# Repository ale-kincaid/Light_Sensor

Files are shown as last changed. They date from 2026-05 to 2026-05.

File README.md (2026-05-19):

# Light Sensor Embedded System

This repository contains the firmware and documentation for a light-sensing embedded system built around an STM32 microcontroller and a custom PCB. The project originally began as a school embedded systems project and has since been transferred to this personal repository for continued development, documentation, and refinement.

The system is designed to measure light intensity using a light-to-frequency sensor, process the signal on an STM32 microcontroller, and support serial communication, timestamping, and data logging for future environmental monitoring use cases.

## Project Status

This project is currently being continued as a personal embedded systems project. The original prototype was developed using an STM32 Nucleo development board, and the current version is being adapted to run on a custom PCB.

Current focus areas include:

- Migrating the firmware from the development board setup to the custom PCB
- Verifying UART communication on the custom hardware
- Testing sensor measurements from the PCB-mounted light sensor
- Improving flash logging and timestamped data storage
- Preparing the system for a more complete standalone prototype

## Project Overview

The goal of this project is to build a compact embedded light sensor capable of collecting and storing light measurements. The system uses a light-to-frequency sensor whose output frequency changes based on the amount of detected light. The STM32 measures this frequency using timer input capture and can communicate with a user through a UART command interface.

This type of system could be used for environmental monitoring, light pollution studies, outdoor sensing, or as a foundation for a low-power remote sensor node.

## Features

- STM32-based embedded firmware
- Custom PCB-based hardware design
- Light-to-frequency sensor integration
- Timer input capture for measuring sensor output
- UART serial command interface
- Interrupt-driven UART receive handling
- Circular buffer for incoming commands
- Real-time clock support for timestamps
- Flash memory logging for persistent records
- Command parsing for setting and reading system values
- Prototype-focused hardware and firmware documentation

## Hardware

The current hardware design uses a custom PCB instead of only relying on the STM32 Nucleo development board. The PCB is designed to support the core sensing, communication, and power components needed for the light sensor prototype.

### Main Hardware Components

| Component | Purpose |
|---|---|
| STM32 microcontroller | Main embedded controller |
| TSL237 light-to-frequency sensor | Measures light through frequency output |
| Custom PCB | Integrates the sensor, controller, power, and communication hardware |
| UART connector | Serial communication and debugging |
| RTC support | Provides time and date information for logged records |
| Battery holder / power input | Supports standalone prototype development |
| Oscillator / clock components | Supports timing requirements |
| Debug/programming interface | Allows firmware flashing and debugging |

## Software / Firmware Stack

- **Language:** Embedded C
- **IDE:** STM32CubeIDE
- **Configuration Tool:** STM32CubeMX
- **Platform:** STM32
- **Communication:** UART
- **Key Peripherals:**
  - GPIO
  - UART / USART
  - Timers
  - RTC
  - Flash memory
  - Interrupts

## System Architecture

```text
Light Source
    |
    v
TSL237 Light-to-Frequency Sensor
    |
    v
STM32 Timer Input Capture
    |
    v
Embedded Firmware
    |
    +--> UART Command Interface
    |
    +--> RTC Timestamping
    |
    +--> Flash Data Logging
    |
    v
Stored or Transmitted Sensor Records

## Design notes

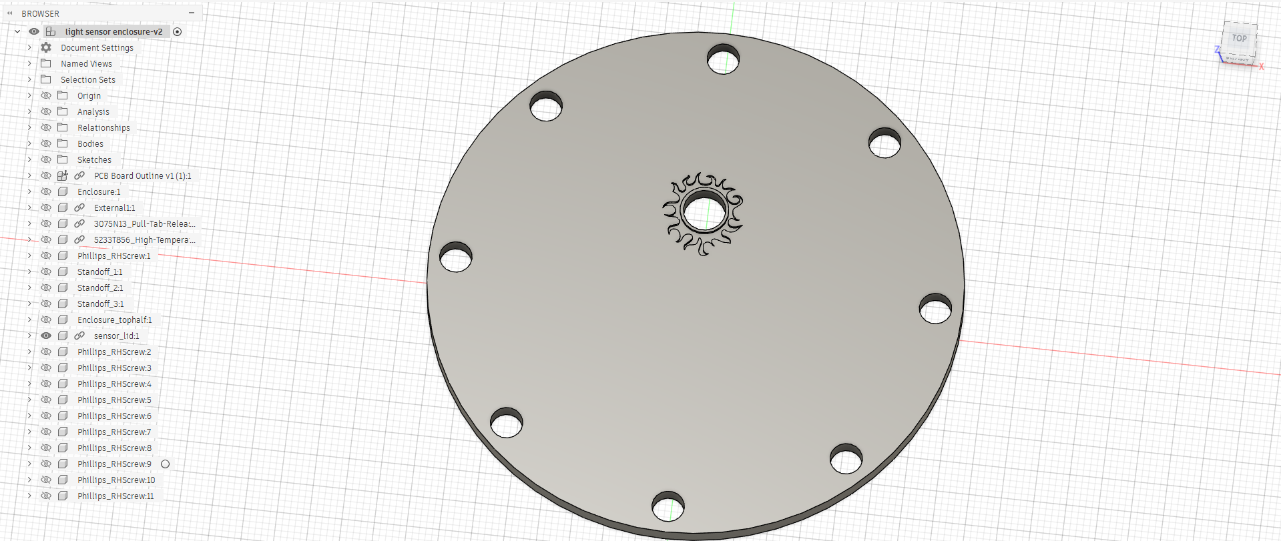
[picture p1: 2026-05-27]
AutodeskFusion/light_sensor_lid_sc.png

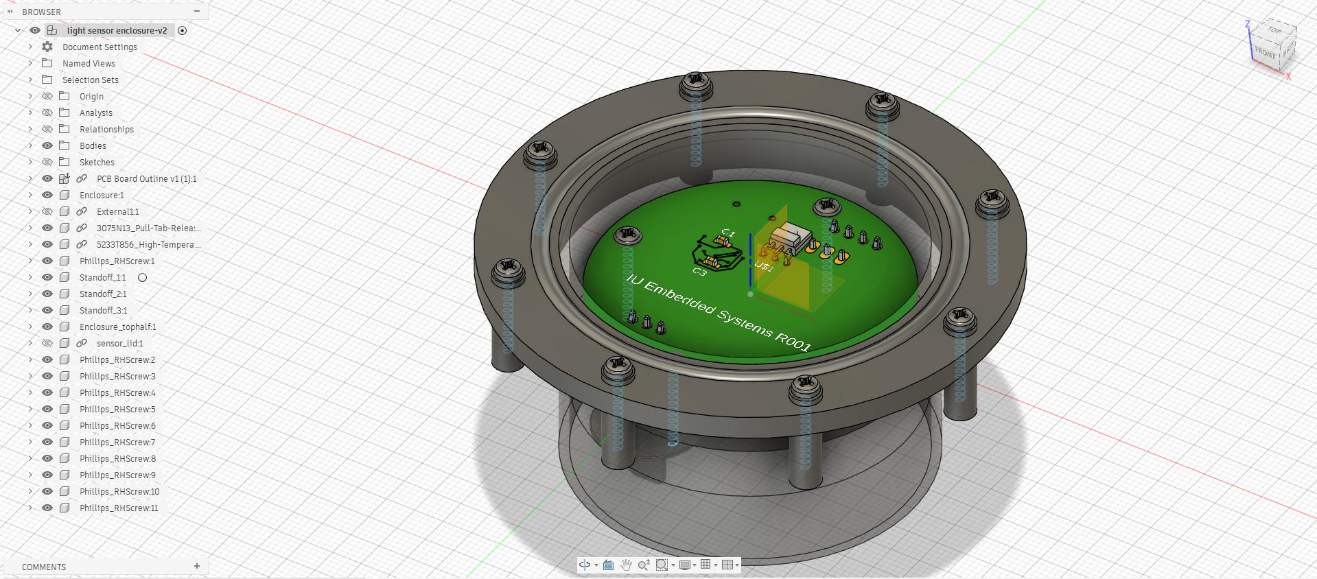
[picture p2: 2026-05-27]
AutodeskFusion/light_sensor_enclosure_sc.png

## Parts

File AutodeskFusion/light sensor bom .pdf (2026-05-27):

Name | light sensor bom
Exported by | akincai@iu.edu
Time of Export | 3/31/26 11:53AM
BT1 1 Holder Coin Cell 20mm Smd MPD BK-912-TR DigiKey C1,C2,C4 3 CAPACITOR, 0.1uF Murata Electronics RCER71H104K0K1H03B DigiKey DigiKey | $0.39 $0.39
$0.16 | $0.49
C3 | 1 CAPACITOR, 1uF | Murata Electronics | RCER71H105K2K1H03B | $0.23 | $0.23
J1 | 1 | | Samtec | FTSH-107-01-L-DV-K-A-P-TR | $1.92 | $1.92
J2 | 1 | XH Connector Top Entry - 4POS JST Sales America Inc. B4B-XH-A | $0.09 | $0.09
J3 | 1 | XH Connector Top Entry - 3POS JST Sales America Inc. B3B-XH-A | $0.08 | $0.08
R1, R2 | 2 | RESISTOR, 200 Ohms | YAGEO | RC0603FR-07200RL | $0.01 | $0.01
TP1, TP2 | 2 | Test pad | Keystone Electronics | 5011 | $0.19 | $0.38
U$1 | 1 | Light Sensor | ams-OSRAM USA INC. TSL237S-LF | ≈ $3.00 | ≈ $3.00
U$2 | 1 | | Würth Elektronik | 61300311121 | $0.08 | $0.08
U1 | 1 | | STMicroelectronics | UFQFPN 32 5x5x0.55 mm | $2.14 | $2.14
XTAL1 | 1 | Oscillator at 32.768 kHz | Epson Timing | | $3.94 | $3.94

CONN HEADER SMD 14POS 1.27

CONN HEADER VERT 3POS 2.54M Ultra-low-power with FPU Arm C TG-3541CE_32_7680KXB3_E

Reference Designators Quantity | Description | Manufacturer | Manufacturer Part Number Distributor | Unit Cost | Extended Cost

Mouser
DigiKey
DigiKey
DIgiKey
DigiKey
DigiKey
DigiKey
STMicroelectronics
Mouser

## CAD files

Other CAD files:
AutodeskFusion/Light_Sensor_Design_all.f3z

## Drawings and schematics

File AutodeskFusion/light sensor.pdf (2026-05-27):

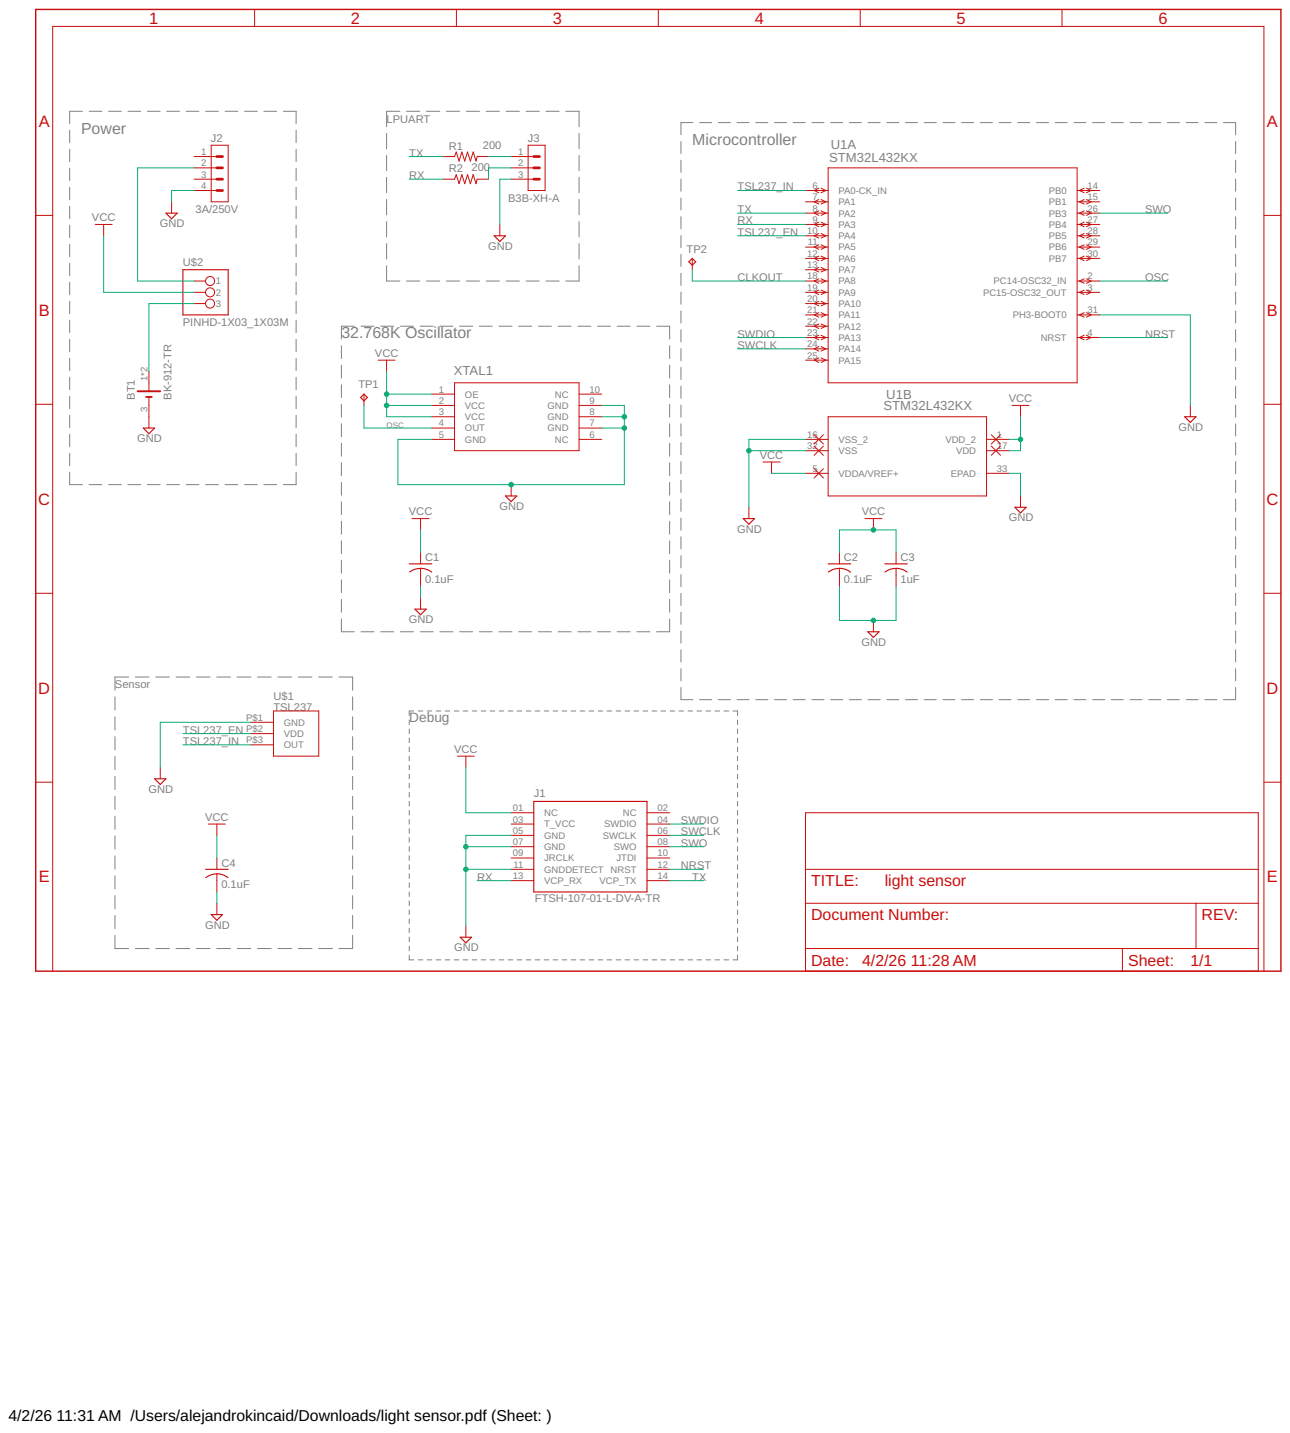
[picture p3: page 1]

Document Number: | REV:

Date: 4/2/26 11:28 AM | Sheet: 1/1

4/2/26 11:31 AM /Users/alejandrokincaid/Downloads/light sensor.pdf (Sheet: )

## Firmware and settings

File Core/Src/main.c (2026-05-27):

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
/* Includes ------------------------------------------------------------------*/
#include "main.h"

/* USER CODE BEGIN Includes */
#include <retarget.h>
#include <stdio.h>
#include <string.h>
#include <stdlib.h>
#include <stm32l4xx_ll_usart.h>

#include "command.h"
#include "queue.h"
#include "rtc.h"
#include "temperature.h"
#include "battery.h"
#include "sample.h"
/* USER CODE END Includes */

/* USER CODE BEGIN PD */
#define CLEAR_SCREEN "\033[2J\033[H"
/* USER CODE END PD */

/* USER CODE BEGIN PM */
int MAX_COMMAND_LEN = 32;
/* USER CODE END PM */

ADC_HandleTypeDef hadc1;

RTC_HandleTypeDef hrtc;

TIM_HandleTypeDef htim2;

UART_HandleTypeDef huart2;

/* USER CODE BEGIN PV */
queue_t rx_queue;

volatile uint8_t alarm = 0;
/* USER CODE END PV */

void SystemClock_Config(void);
static void MX_GPIO_Init(void);
static void MX_TIM2_Init(void);
static void MX_USART2_UART_Init(void);
static void MX_ADC1_Init(void);
static void MX_RTC_Init(void);
/* USER CODE BEGIN 0 */
enum states {FIRST_EDGE, SECOND_EDGE};
/* USER CODE END 0 */

/**
  * @brief  The application entry point.
  * @retval int
  */
int main(void)
{

  /* MCU Configuration--------------------------------------------------------*/

  /* Reset of all peripherals, Initializes the Flash interface and the Systick. */
  HAL_Init();

  /* USER CODE BEGIN Init */
  init_queue(&rx_queue);
  /* USER CODE END Init */

  /* Configure the system clock */
  SystemClock_Config();

  /* Initialize all configured peripherals */
  MX_GPIO_Init();
  MX_TIM2_Init();
  MX_USART2_UART_Init();
  MX_ADC1_Init();
  MX_RTC_Init();
  /* USER CODE BEGIN 2 */
  RetargetInit(&huart2);

  printf(CLEAR_SCREEN);
  printf("\n\r*********************\n\rSystem Up and Running\n\r");
  prompt();
  uint8_t command[MAX_COMMAND_LEN];
  int command_length = 0;
  /* USER CODE END 2 */

  /* Infinite loop */
  /* USER CODE BEGIN WHILE */

  while(1)
  {
	  if (get_command(command)) {
		  //		command_length = delspace(command);
		  if (command_length != -1) {
			  if(execute_command(command)) {
				  printf("NOK\n\r");
				  prompt();
				  printf("\n\r");
			  }
			  else {
				  prompt();
			  }
		  }
		  else {
			  printf("NOK\n\r");
		  }
	  }
	  if (alarm){
		  printf("\n\rAlarm happened\n\r");
		  prompt();
		  alarm = 0;
		  sample();
	  }
  }
    /* USER CODE END WHILE */

}

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


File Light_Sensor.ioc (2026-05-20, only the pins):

Mcu.UserName=STM32L432KCUx
PA0.Signal=S_TIM2_CH1
PA2.Signal=USART2_TX
PA3.Signal=USART2_RX
PA4.Signal=GPIO_Output
PA8.Signal=RCC_MCO

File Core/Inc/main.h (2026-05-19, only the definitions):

#define TSL237_IN_Pin GPIO_PIN_0
#define TSL237_IN_GPIO_Port GPIOA
#define VCP_TX_Pin GPIO_PIN_2
#define VCP_TX_GPIO_Port GPIOA
#define VCP_RX_Pin GPIO_PIN_3
#define VCP_RX_GPIO_Port GPIOA
#define TSL237_EN_Pin GPIO_PIN_4
#define TSL237_EN_GPIO_Port GPIOA
#define SWDIO_Pin GPIO_PIN_13
#define SWDIO_GPIO_Port GPIOA
#define SWCLK_Pin GPIO_PIN_14
#define SWCLK_GPIO_Port GPIOA
#define SWO_Pin GPIO_PIN_3
#define SWO_GPIO_Port GPIOB

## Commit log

2026-05-19 Some commands work. Need to fix ADC.
    [Light_Sensor.ioc, adc.c, flash.c]
2026-05-19 Fixed adc conversions. Command works
    [adc.c, main.c]

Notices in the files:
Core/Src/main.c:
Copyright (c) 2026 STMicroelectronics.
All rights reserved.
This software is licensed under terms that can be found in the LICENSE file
